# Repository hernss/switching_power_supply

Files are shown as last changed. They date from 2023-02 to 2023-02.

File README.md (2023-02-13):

# Descripción del proyecto:

El objetivo de este proyecto es desarrollar una fuente switching de voltaje variable basada en el integrado TPS54331 de Texas Instruments. Como entrada vamos a poder utilizar una fuente ATX estándar de PC o una fuentes del estilo notebook de hasta 24 volts. La fuente proveerá una salida variable entre 1.5 volts y 24 volts la cual es ajustada mediante un potenciómetro. En el caso de alimentarse con una fuente ATX también se va a disponer de las salidas de 3,3v +5v + 12v -5v -12v.
La salida esta implementadas con borneras en dos piezas, quedando el macho adherido al PCB y una parte removible a la cual se podrán conectar cables mediante tornillos.

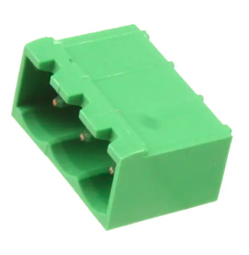
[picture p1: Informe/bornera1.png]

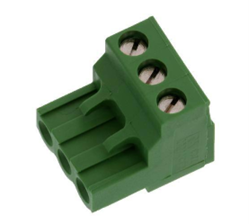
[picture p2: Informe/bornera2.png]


# Calculo de los componentes:
## Bloqueo por bajo voltaje de entrada:

* R1=  (V_START- V_STOP)/(3µA)=(6.8V-6.5V)/(3µA)=100KΩ
* R2=V_EN/((V_START- V_EN)/R1+1µA)=1.25V/((6.8V-1.25V)/100KΩ+1µA)=22123Ω

Asumo R2 = 22KΩ

## Arranque Suave:

T_SS (ms)=(C_SS (nF)x V_REF (V))/(I_SS (mA))=(10 x 0.8)/2=4 ms

## Calculo de R5 y R6:

Según la hoja de datos recomienda utilizar una resistencia de alrededor de 10K para R5, por esto asumimos inicialmente a R5 como 10K

R6 la calculamos según la siguiente ecuación:

R6=(R5 x V_REF)/(V_OUT-V_REF )

## Para obtener 4.5V a la salida:

R6=(10KΩ x 0.8V)/(4.5V-0.8V)=2162Ω 

Asumo R6 = 2.2KΩ por ser el valor comercial más cercano.

V_OUT=V_REF  x (R5/R6+1)=0.8V x (10KΩ/2.2KΩ+1)=4.44V

## Para obtener 6V a la salida:
R6=(10KΩ x 0.8V)/(6V-0.8V)=1538Ω

Como el valor comercial más cercano está muy lejos del valor que necesitamos vamos a cambiar R5 a 12K y vamos a repetir los cálculos.

R6=(12KΩ x 0.8V)/(6V-0.8V)=1845Ω

Asumo R6 = 1,8KΩ  por ser el valor comercial más cercano.

V_OUT=V_REF  x (R5/R6+1)=0.8V x (12KΩ/1.8KΩ+1)=6.13V

## Valores máximos y mínimos de la tensión de salida:

Si ahora tomamos fijo R5 = 10K y agregamos un potenciómetro de 10K con una resistencia de 330Ω en serie podemos calcular el voltaje máximo y mínimo que podemos tener a la salida.

V_MAX=V_REF  x (R5/〖R6〗_MIN +1)=0.8V x (10KΩ/330Ω+1)=25.04V

V_MIN=V_REF  x (R5/〖R6〗_MAX +1)=0.8V x (10KΩ/10330Ω+1)=1.57V

Cabe aclarar que para obtener el VMAX a la salida, la entrada tiene que tener el voltaje suficiente.

# Diagrama Esquemático:

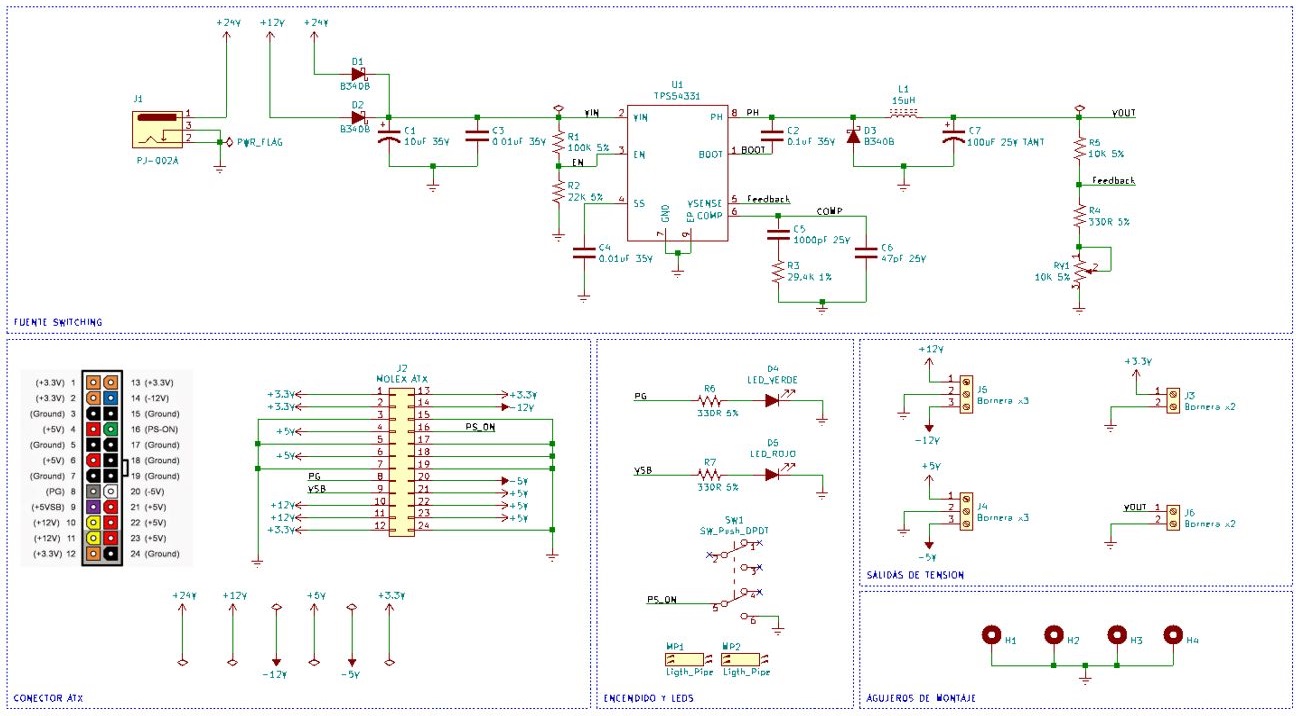
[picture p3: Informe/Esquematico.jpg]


# Circuito impreso

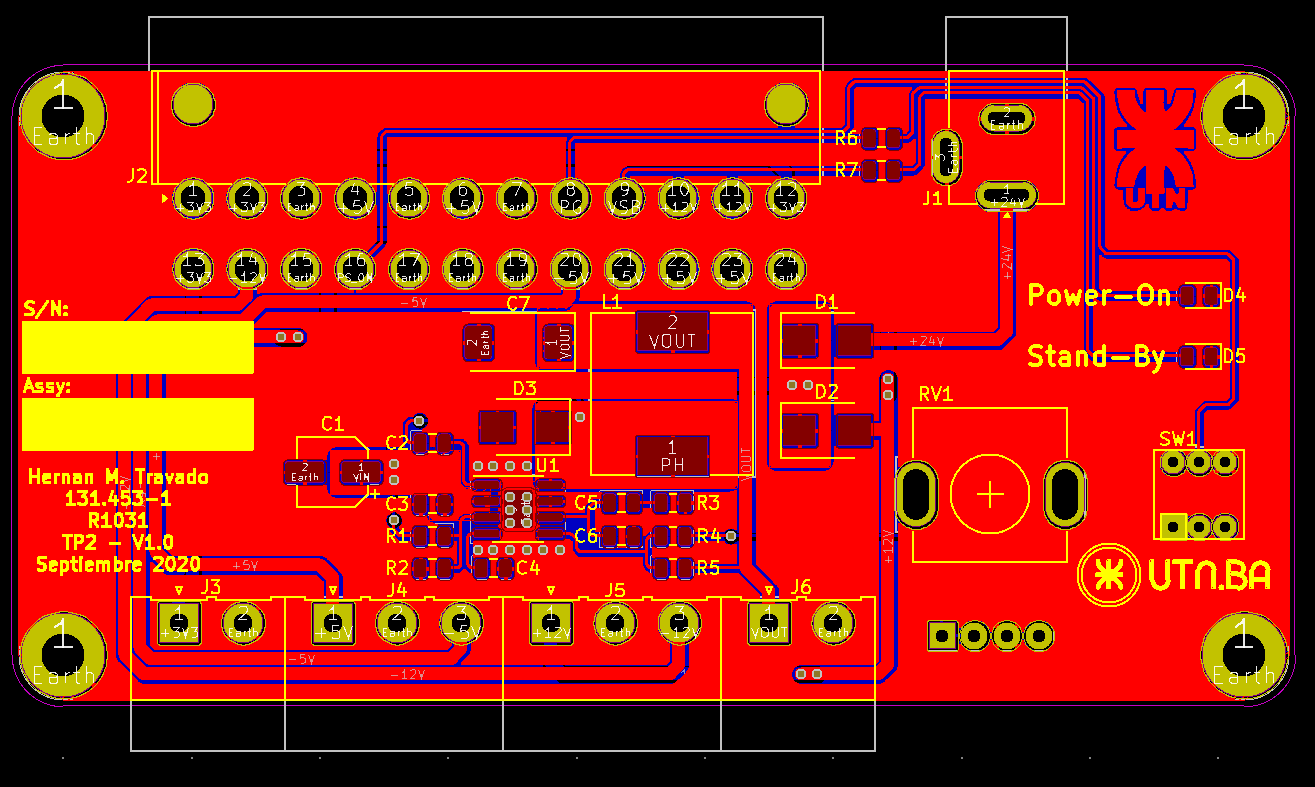
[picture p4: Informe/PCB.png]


# Vista 3D de la placa terminada

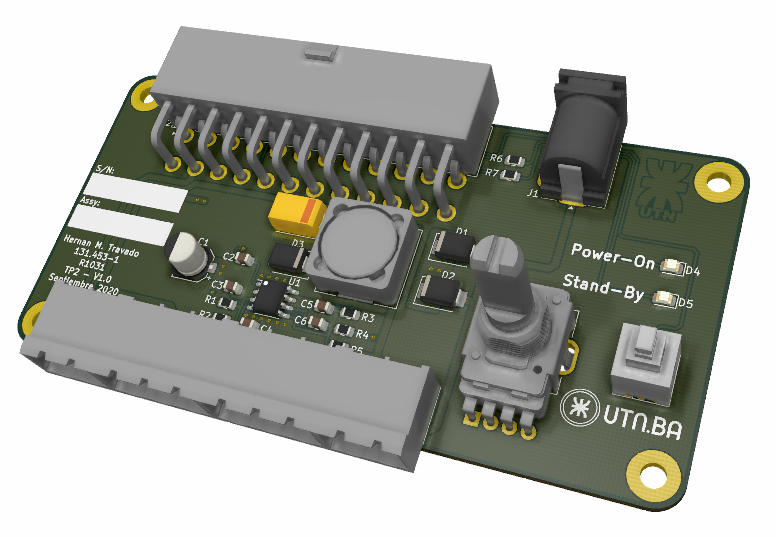
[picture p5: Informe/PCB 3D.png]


# Panelizado del PCB

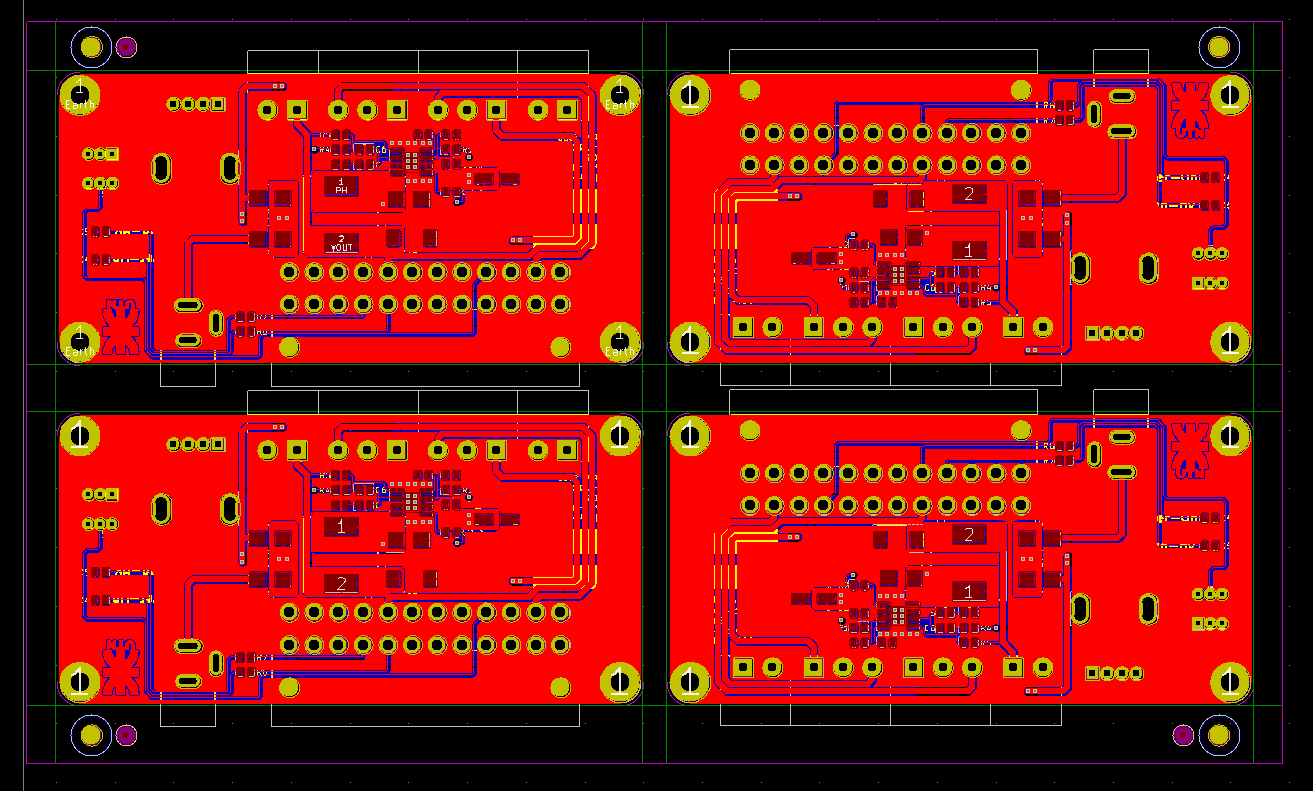
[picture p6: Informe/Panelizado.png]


# Diseño del gabinete

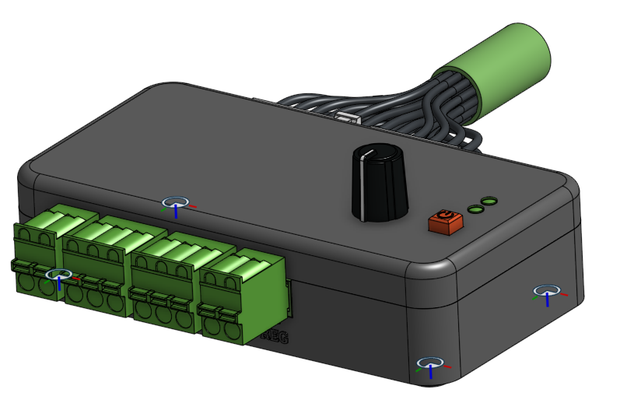
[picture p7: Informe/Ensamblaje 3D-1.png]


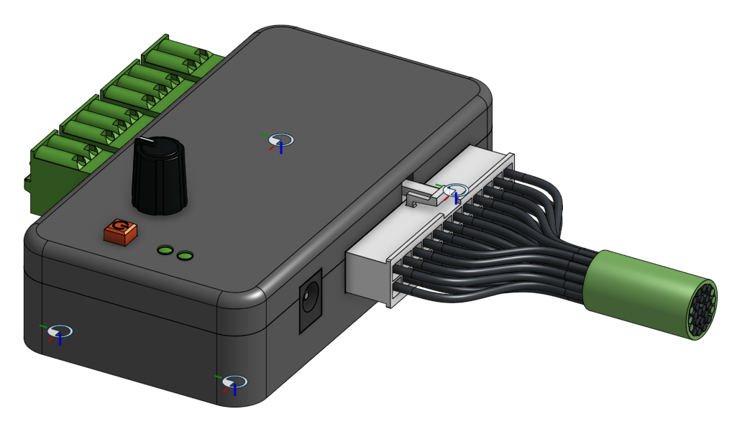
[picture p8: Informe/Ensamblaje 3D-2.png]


# Link a ON-Shape:

https://cad.onshape.com/documents/020dfdbda6882e2ac2e1fa2c/w/ac47c3931b7ff00251a716d9/e/94a10833bc3fe93f9d4dad91

# Lista de Materiales (BOM):

Cantidad	Referencia	Fabricante	Fabricante P/N	Digikey P/N

1	C1	Panasonic Electronic Components	EEE-HB1V100R	PCE4153CT-ND

1	C2	AVX Corporation	08055C104KAT2A	478-1395-1-ND

2	C3, C4	Yageo	CC0805KRX7R9BB103	311-1136-1-ND

1	C5	Samsung Electro-Mechanics	CL21B102KBANNNC	1276-1020-1-ND

1	C6	Samsung Electro-Mechanics	CL21C470JBANNNC	1276-1156-1-ND

1	C7	KEMET	T491X107K025AT	399-8410-1-ND

3	D1, D2, D3	Diodes Incorporated	B340B-13-F	B340B-FDICT-ND

1	D4	Lite-On Inc.	LTST-C170KGKT	160-1414-1-ND

1	D5	Lite-On Inc.	LTST-C171KRKT	160-1427-2-ND

1	J1	CUI Devices	PJ-002A	CP-002A-ND

1	J2	Molex	39299242	WM7334-ND

2	J3, J6	TE Connectivity AMP Connectors	796644-2	A98248-ND

2	J4, J5	TE Connectivity AMP Connectors	796644-3	A98249-ND

1	L1	Bourns Inc.	SRR1260-150M	SRR1260-150MCT-ND

2	MP1, MP2	Visual Communications Company	LFB063CTP	LFB063CTP-ND

1	R1	Yageo	RC0805JR-07100KL	311-100KARCT-ND

1	R2	Yageo	RC0805JR-0722KL	311-22KARCT-ND

1	R3	Yageo	RC0805FR-0729K4L	311-29.4KCRTR-ND

3	R4, R6, R7	Yageo	RC0805JR-07330RL	311-330RARCT-ND

1	R5	Yageo	RC0805JR-0710KL	311-10KARCT-ND

1	RV1	Bourns Inc.	PTV111-3415A-B103	PTV111-3415A-B103-ND

1	SW1	E-Switch	TL2230EEF140	EG6031-ND

1	U1	Texas Instruments	TPS54331DDAR	296-39419-1-ND

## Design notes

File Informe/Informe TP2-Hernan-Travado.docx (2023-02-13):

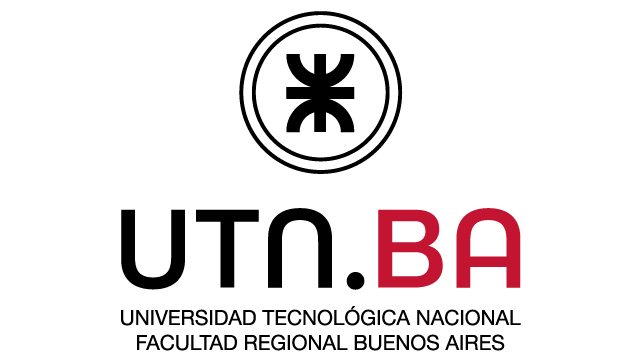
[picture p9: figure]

SISTEMAS DE REPRESENTACIÓN

Trabajo Práctico Nro. 2

Alumno: Hernán Matías Travado

Legajo: 131.453-1

Curso: R1031 – Jueves Tarde

Fecha de Entrega: 27/08/2020

Versión: 1.0

Profesores: Fernando Aló – Francisco Domínguez - Lucas Liaño

Tabla de Contenidos:

# Descripción del proyecto:

El objetivo de este proyecto es desarrollar una fuente switching de voltaje variable basada en el integrado TPS54331 de Texas Instruments. Como entrada vamos a poder utilizar una fuente ATX estándar de PC o una fuentes del estilo notebook de hasta 24 volts. La fuente proveerá una salida variable entre 1.5 volts y 24 volts la cual es ajustada mediante un potenciómetro. En el caso de alimentarse con una fuente ATX también se va a disponer de las salidas de 3,3v +5v + 12v -5v -12v.

La salida esta implementadas con borneras en dos piezas, quedando el macho adherido al PCB y una parte removible a la cual se podrán conectar cables mediante tornillos.

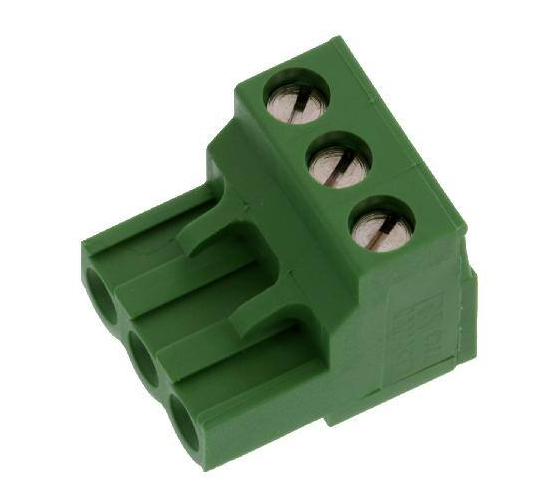
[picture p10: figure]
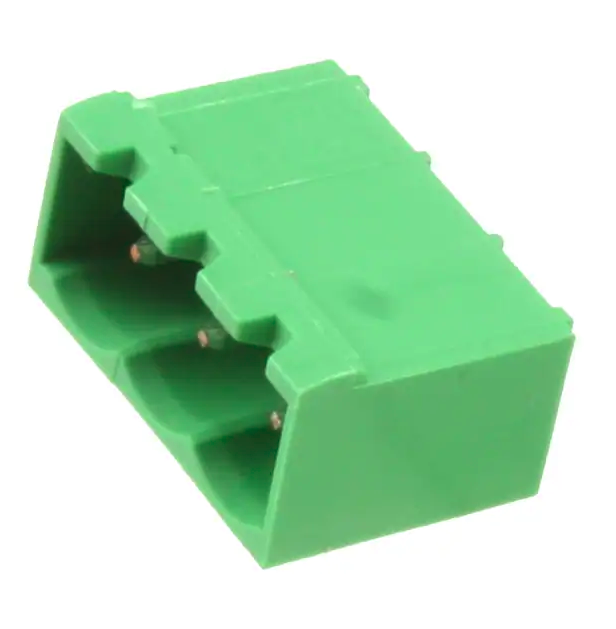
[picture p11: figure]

Detalle de las borneras de salida

# Calculo de los componentes:

## Bloqueo por bajo voltaje de entrada:

R1= (V_(START) - V_(STOP))/(3µA)=(6.8V-6.5V)/(3µA)=100KΩ

R2=(V_(EN))/((V_(START) - V_(EN))/(R1)+1µA)=(1.25V)/((6.8V-1.25V)/(100KΩ)+1µA)=22123Ω

Asumo R2 = 22KΩ

## Arranque Suave:

T_(SS) (ms)=(C_(SS) (nF)x V_(REF) (V))/(I_(SS) (mA))=(10 x 0.8)/2=4 ms

## Calculo de R5 y R6:

Según la hoja de datos recomienda utilizar una resistencia de alrededor de 10K para R5, por esto asumimos inicialmente a R5 como 10K

R6 la calculamos según la siguiente ecuación:

R6=(R5 x V_(REF))/(V_(OUT) -V_(REF))

## Para obtener 4.5V a la salida:

R6=(10KΩ x 0.8V)/(4.5V-0.8V)=2162Ω

Asumo R6 = 2.2KΩ por ser el valor comercial más cercano.

V_(OUT) =V_(REF) x ((R5)/(R6)+1)=0.8V x ((10KΩ)/(2.2KΩ)+1)=4.44V

## Para obtener 6V a la salida:

R6=(10KΩ x 0.8V)/(6V-0.8V)=1538Ω

Como el valor comercial más cercano está muy lejos del valor que necesitamos vamos a cambiar R5 a 12K y vamos a repetir los cálculos.

R6=(12KΩ x 0.8V)/(6V-0.8V)=1845Ω

Asumo R6 = 1,8KΩ por ser el valor comercial más cercano.

V_(OUT) =V_(REF) x ((R5)/(R6)+1)=0.8V x ((12KΩ)/(1.8KΩ)+1)=6.13V

## Valores máximos y mínimos de la tensión de salida:

Si ahora tomamos fijo R5 = 10K y agregamos un potenciómetro de 10K con una resistencia de 330Ω en serie podemos calcular el voltaje máximo y mínimo que podemos tener a la salida.

V_(MAX) =V_(REF) x ((R5)/(R6_(MIN))+1)=0.8V x ((10KΩ)/(330Ω)+1)=25.04V

V_(MIN) =V_(REF) x ((R5)/(R6_(MAX))+1)=0.8V x ((10KΩ)/(10330Ω)+1)=1.57V

Cabe aclarar que para obtener el VMAX a la salida, la entrada tiene que tener el voltaje suficiente.

# Estructura del ZIP entregado:

TPS54331
├── BOM | Lista de Materiales | Archivos .xls /.ods con la lista de materiales del proyecto
├── Checklist | Checklist | Checklist actualizado del proyecto
├── Gabinete | Gabinete | Proyecto onShape con el gabinete del PCB del proyecto
├── Informe | Informe | Informe de todo el proyecto en PDF
└── TPS54331 | Proyecto | Archivos de diseño del proyecto en Kicad
├── footprints | Librerías de footprints | Carpeta contenedora de librerías de footprint
│ ├── LogoUTN.pretty | Librería del proyecto | Librería de footprints con logos de la facultad
│ └── tp2.pretty | Librería del proyecto | Librería de footprints propias del proyecto
├── gerber | Gerbers | Gerbers, archivos de fabricación, drill files, etc.
├── libraries | Librería del proyecto | Librería de símbolos propias del proyecto
├── modelos3D | Modelos en 3D | Archivos .step, .stp o .wrl de los componentes
├── output | Output | Contiene la BOM en CSV y los esquemáticos en PDF
└── panel | Panel | Contiene el Panelizado del PCB
├── gerber | Gerbers | Gerbers, drill files, etc. del panel
└── modelos3D | Modelos en 3D | Archivos .step, .stp o .wrl de los componentes

# Diagrama Esquemático:

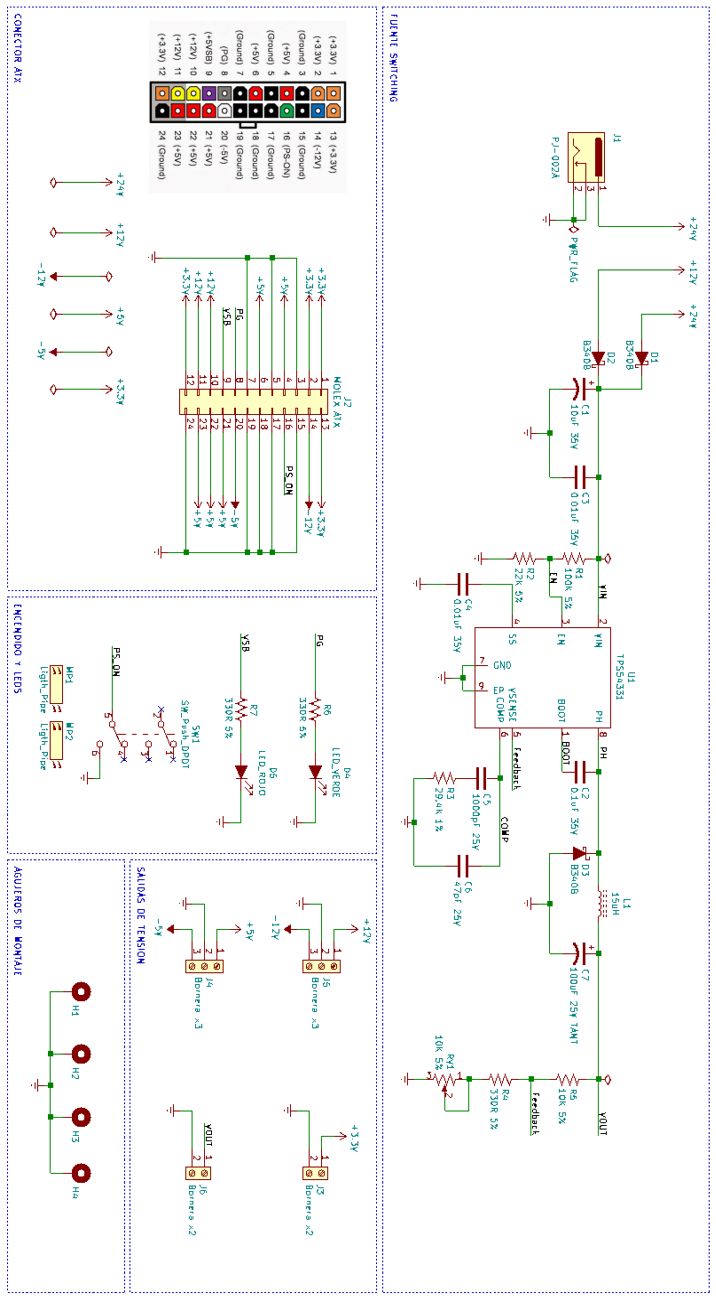
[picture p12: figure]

# Circuito Impreso:


# Vista 3D de la placa terminada:


# Panelizado del PCB:


# Lista de Materiales (BOM):

Cantidad | Referencia | Fabricante | Fabricante P/N | Digikey P/N
1 | C1 | Panasonic Electronic Components | EEE-HB1V100R | PCE4153CT-ND
1 | C2 | AVX Corporation | 08055C104KAT2A | 478-1395-1-ND
2 | C3, C4 | Yageo | CC0805KRX7R9BB103 | 311-1136-1-ND
1 | C5 | Samsung Electro-Mechanics | CL21B102KBANNNC | 1276-1020-1-ND
1 | C6 | Samsung Electro-Mechanics | CL21C470JBANNNC | 1276-1156-1-ND
1 | C7 | KEMET | T491X107K025AT | 399-8410-1-ND
3 | D1, D2, D3 | Diodes Incorporated | B340B-13-F | B340B-FDICT-ND
1 | D4 | Lite-On Inc. | LTST-C170KGKT | 160-1414-1-ND
1 | D5 | Lite-On Inc. | LTST-C171KRKT | 160-1427-2-ND
1 | J1 | CUI Devices | PJ-002A | CP-002A-ND
1 | J2 | Molex | 39299242 | WM7334-ND
2 | J3, J6 | TE Connectivity AMP Connectors | 796644-2 | A98248-ND
2 | J4, J5 | TE Connectivity AMP Connectors | 796644-3 | A98249-ND
1 | L1 | Bourns Inc. | SRR1260-150M | SRR1260-150MCT-ND
2 | MP1, MP2 | Visual Communications Company | LFB063CTP | LFB063CTP-ND
1 | R1 | Yageo | RC0805JR-07100KL | 311-100KARCT-ND
1 | R2 | Yageo | RC0805JR-0722KL | 311-22KARCT-ND
1 | R3 | Yageo | RC0805FR-0729K4L | 311-29.4KCRTR-ND
3 | R4, R6, R7 | Yageo | RC0805JR-07330RL | 311-330RARCT-ND
1 | R5 | Yageo | RC0805JR-0710KL | 311-10KARCT-ND
1 | RV1 | Bourns Inc. | PTV111-3415A-B103 | PTV111-3415A-B103-ND
1 | SW1 | E-Switch | TL2230EEF140 | EG6031-ND
1 | U1 | Texas Instruments | TPS54331DDAR | 296-39419-1-ND

# Link a Octopart:

https://octopart.com/bom-tool/RoDDKawv

# Gabinete en 3D:


# Link a ON-Shape:

https://cad.onshape.com/documents/020dfdbda6882e2ac2e1fa2c/w/ac47c3931b7ff00251a716d9/e/94a10833bc3fe93f9d4dad91

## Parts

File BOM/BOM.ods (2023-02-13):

Qty | Reference(s) | Value | Datasheet | Digikey P/N | Manufacturer | Manufacturer P/N | Mouser P/N
1 | C1 | 10uF 35V | https://industrial.panasonic.com/cdbs/www-data/pdf/RDE0000/ABA0000C1157.pdf | PCE4153CT-ND | Panasonic Electronic Components | EEE-HB1V100R
1 | C2 | 0.1uF 35V | http://datasheets.avx.com/X7RDielectric.pdf | 478-1395-1-ND | AVX Corporation | 08055C104KAT2A
2 | C3, C4 | 0.01uF 35V | https://www.yageo.com/upload/media/product/productsearch/datasheet/mlcc/UPY-GPHC_X7R_6.3V-to-50V_18.pdf | 311-1136-1-ND | Yageo | CC0805KRX7R9BB103
1 | C5 | 1000pF 25V | https://media.digikey.com/pdf/Data%20Sheets/Samsung%20PDFs/CL_Series_MLCC_ds.pdf | 1276-1020-1-ND | Samsung Electro-Mechanics | CL21B102KBANNNC
1 | C6 | 47pF 25V | https://media.digikey.com/pdf/Data%20Sheets/Samsung%20PDFs/CL_Series_MLCC_ds.pdf | 1276-1156-1-ND | Samsung Electro-Mechanics | CL21C470JBANNNC
1 | C7 | 100uF 25V TANT | https://api.kemet.com/component-edge/download/datasheet/T491X107K025AT.pdf | 399-8410-1-ND | KEMET | T491X107K025AT
3 | D1, D2, D3 | B340B | https://media.digikey.com/pdf/Data%20Sheets/Diodes%20PDFs/B320B-B360B_Rev10-2.pdf | B340B-FDICT-ND | Diodes Incorporated | B340B-13-F | 621-B340B-F
1 | D4 | LED_VERDE | http://optoelectronics.liteon.com/upload/download/DS22-2000-073/LTST-C170KGKT.pdf | 160-1414-1-ND | Lite-On Inc. | LTST-C170KGKT
1 | D5 | LED_ROJO | http://optoelectronics.liteon.com/upload/download/DS22-2000-073/LTST-C170KGKT.pdf | 160-1427-2-ND | Lite-On Inc. | LTST-C171KRKT
4 | H1, H2, H3, H4 | MountingHole_Pad | ~
1 | J1 | PJ-002A | https://www.cuidevices.com/product/resource/digikeypdf/pj-002a.pdf | CP-002A-ND | CUI Devices | PJ-002A
1 | J2 | MOLEX ATX | https://www.molex.com/pdm_docs/sd/039299022_sd.pdf | WM7334-ND | Molex | 39299242
2 | J3, J6 | Bornera x2 | https://www.te.com/commerce/DocumentDelivery/DDEController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 | A98248-ND | TE Connectivity AMP Connectors | 796644-2
2 | J4, J5 | Bornera x3 | https://www.te.com/commerce/DocumentDelivery/DDEController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 | A98249-ND | TE Connectivity AMP Connectors | 796644-3
1 | L1 | 15uH | https://www.bourns.com/docs/Product-Datasheets/SRR1260.pdf | SRR1260-150MCT-ND | Bourns Inc. | SRR1260-150M
2 | MP1, MP2 | Ligth_Pipe | http://www.vcclite.com/_pdf/LFBSeries.pdf | LFB063CTP-ND | Visual Communications Company - VCC | LFB063CTP
1 | R1 | 100K 5% | https://www.yageo.com/upload/media/product/productsearch/datasheet/rchip/PYu-RC_Group_51_RoHS_L_10.pdf | 311-100KARCT-ND | Yageo | RC0805JR-07100KL
1 | R2 | 22K 5% | https://www.yageo.com/upload/media/product/productsearch/datasheet/rchip/PYu-RC_Group_51_RoHS_L_10.pdf | 311-22KARCT-ND | Yageo | RC0805JR-0722KL
1 | R3 | 29.4K 1% | https://www.yageo.com/upload/media/product/productsearch/datasheet/rchip/PYu-RC_Group_51_RoHS_L_10.pdf | 311-29.4KCRTR-ND | Yageo | RC0805FR-0729K4L
3 | R4, R6, R7 | 330R 5% | https://www.yageo.com/upload/media/product/productsearch/datasheet/rchip/PYu-RC_Group_51_RoHS_L_10.pdf | 311-330RARCT-ND | Yageo | RC0805JR-07330RL
1 | R5 | 10K 5% | https://www.yageo.com/upload/media/product/productsearch/datasheet/rchip/PYu-RC_Group_51_RoHS_L_10.pdf | 311-10KARCT-ND | Yageo | RC0805JR-0710KL
1 | RV1 | 10K 5% | https://www.bourns.com/docs/Product-Datasheets/PTVPTT.pdf | PTV111-3415A-B103-ND | Bourns Inc. | PTV111-3415A-B103
1 | SW1 | SW_Push_DPDT | https://sten-eswitch-13110800-production.s3.amazonaws.com/system/asset/product_line/data_sheet/61/TL2201.pdf | EG6031-ND | E-Switch | TL2230EEF140
1 | U1 | TPS54331 | http://www.ti.com/general/docs/suppproductinfo.tsp?distId=10 | 296-39419-1-ND | Texas Instruments | TPS54331DDAR

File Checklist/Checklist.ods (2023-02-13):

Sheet: Completa
# | Ubicación de componentes | Comentarios | Cumple / No cumple / No aplica
1 | Orientación consistente de componentes SMD |  | Cumple
2 | Espacio para herramientas de retrabajo y extraccion de ICs |  | Cumple
3 | Verificar componentes polarizados |  | Cumple
4 | Utilizar grilla de 50 mil (o 1.25mm) para componentes THT y 20 mils (o 0.5mm) para SMD |  | Cumple
5 | Verificar orientación de todos los conectores |  | Cumple
6 | Verificar espacio mínimo entre cuerpo de componentes |  | Cumple
7 | Capacitores de desacople (bypass) cerca de pines de alimentación de los IC |  | Cumple
8 | Verificar terminadores en serie cercanos a la fuente |  | Cumple
9 | Drivers I/O cercanos a donde las señales abandonan el PCB |  | No Aplica
10 | Pistas de alimentación y test points, todos etiquetados. | No se utilizaron testpoints. | Cumple
11 | Filtros EMI y RFI lo más cerca posible a puntos de entrada y salida en áreas blindadas. | No se utilizaron filtros EMI ni RFI | No Aplica
12 | Verificar que los potenciómetros incrementar la cantidad controlada en sentido de las agujas del reloj. |  | Cumple
13 | Verificar si los orificios de montaje deben estar aislados eléctricamente o no. | Los orificios de montaje estan conectados a la masa del circuito. | Cumple
14 | Verificar distancia de seguridad de los orificios de montaje hacia otros componentes. |  | Cumple
15 | Verificar factor de forma de los pads SMD. |  | Cumple
16 | Fiduciales locales y en panel para ensamle automático. | No se colocaron fiduciales en la placa, solo se colocaron en el panel | Cumple
17 | Distancia de seguridad suficiente para ICs con zócalo. | No hay ICs con zocalo | No Aplica
# | Ruteo/pistas | Comentarios | Cumple / No cumple / No aplica
18 | Comunes digitales y analógicos unidos en un solo punto. | No hay lineas analogicas. | No Aplica
19 | Verificar pistas debajo de componentes ruidosos o sensibles. |  | No Aplica
20 | No ubicar vias debajo de resistores de metalfilm u otros componentes con aislación pobre. |  | Cumple
21 | Verificar pistas susceptibles a puentes de soldadura. |  | Cumple
22 | Verificar pistas sin conexión en un extremo, a menos que sea a propósito. |  | Cumple
23 | Asegurar que el CAD unifica o no señales Vcc/Vdd y Vss/GND según lo requiera el diseño. |  | Cumple
24 | Utilizar múltiples vías en pistas de alta corriente y/o baja impedancia. | Se utilizaron dos vias en las pistas de alimentacion | Cumple
25 | Observar keepout de componentes y pistas. | No hay componentes con zonas de keepout | No Aplica
26 | Utilizar planos de GND donde sea posible. |  | Cumple
# | Dimensiones | Comentarios | Cumple / No cumple / No aplica
27 | Diámetro de orificios debe considerar el metalizado. |  | Cumple
28 | Diámetro de orificios más grande que el diámetro de pata al menos en 10 mils. |  | Cumple
29 | Ancho de texto en silkscreen 0.20mm o más. |  | Cumple
30 | Pad al menos 0.4mm más grande que drill. |  | Cumple
31 | Componentes ubicados al menos a 1mm del borde del PCB. | A excepcion de las borneras ya que estas sobresalen del gabinete | Cumple
32 | Test point ubicados al menos a 5mm del borde del PCB. | No se colocaron testpoints en la placa | No Aplica
33 | Pistas al menos a 0.5mm del borde del PCB. |  | Cumple
34 | Tolerancia de drills especificada. | No se necesita trabajar con tolerancias especiales | No Aplica
35 | Tolerancia de máscara antisoldante especificada. | No se necesita trabajar con tolerancias especiales | No Aplica
36 | Tolerancia de pistas especificada. | No se necesita trabajar con tolerancias especiales | No Aplica
37 | Tolerancia de serigrafía especificada. | No se necesita trabajar con tolerancias especiales | No Aplica
38 | Ancho de pista suficiente para la corriente que conduce. |  | Cumple
39 | Distancia suficiente entre pistas de alto voltaje. | No hay señales de alto voltaje | No Aplica
# | Serigrafía (silkscreen) | Comentarios | Cumple / No cumple / No aplica
40 | Evitar serigrafía sobre vías u orificios. |  | Cumple
41 | Todos los textos y leyendas legibles en una o dos direcciones. |  | Cumple
42 | Logo de la compañía en serigrafía y/o en cobre (logo de la facultad en nuestro caso) |  | Cumple
43 | Nota de copyright en PCB. | No tiene copyright | No Aplica
44 | Fecha en PCB. |  | Cumple
45 | Número de parte en PCB. (en nuesto caso TP1/TP2, etc) |  | Cumple
46 | Revisión del PCB en serigrafía. (v1.0 o R01) |  | Cumple
47 | Espacio para revisión de montaje en serigrafía. (ASSY) |  | Cumple
48 | Espacio para número de serie en serigrafía. (S/N) |  | Cumple
49 | Ubicar todo el texto de la serigrafía de manera tal que sea legible cuando los componentes están montados. |  | Cumple
50 | Todos los ICs deben tener el pin 1 debidamente marcado y visible con el IC instalado. |  | Cumple
51 | ICs de muchos pines deberían tener los pines extremos numerados para facilitar su identificación. | No hay ICs con muchos pines | No Aplica
52 | Marcas cada 5 o 10 pines en ICs o conectores de muchos pines para facilitar su identificación. | No hay ICs con muchos pines | No Aplica
# | Otros | Comentarios | Cumple / No cumple / No aplica
53 | Utilizar DRC y ERC habilitados en el CAD. (chequeo de errores en esquemático y PCB) | Ambos libres de errores | Cumple
54 | Tomar las precauciones necesarias en circuitos de alta frecuencia. | No es un circuito de alta frecuencia | No Aplica
55 | Colocar conectores y pines extra en prototipos para pruebas, por si es necesario. | No es necesarios agregar ningun pin extra | No Aplica
56 | Verificar dimensiones y formas de orificios en conectores raros (rectangulares, ovalados). |  | Cumple
57 | Verificar si la máscara antisoldante cubre o no cubre las vías. | La mascara antisoldando cubre las vias | Cumple
58 | No rutear ángulos agudos. |  | Cumple
59 | Verificar profundidad de la máscara antisoldante. |  | Cumple
60 | Verificar el netlist manualmente o por inspección visual. |  | Cumple
61 | Verificar si el origen de orificios es un pad de referencia.
62 | Anotar en layer auxiliar ancho del PCB, material y espesor del cobre. |  | Cumple
63 | Utilizar aislamiento térmico (thermal relief) en capas internas de distribución de alimentación. |  | Cumple
64 | Verificar que las aperturas para pasta de estaño sean del tamaño adecuado. |  | Cumple
65 | Verificar si se permiten blind/buried vias en PCB multicapa. | No se utilizaron ese tipo de vias | No Aplica
66 | Definir correctamente el panelizado del PCB. |  | Cumple
67 | Encapsulados metálicos de cristales de alta frecuencia deberían conectarse a GND. | No hay cristales de alta frecuencia en la placa | No Aplica

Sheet: Reducida
# | Ubicación de componentes | Comentarios | Cumple / No cumple / No aplica
1 | Orientación consistente de componentes SMD
2 | Espacio para herramientas de retrabajo y extraccion de ICs
3 | Verificar componentes polarizados
4 | Utilizar grilla de 50 mil (o 1.25mm) para componentes THT y 20 mils (o 0.5mm) para SMD
5 | Verificar orientación de todos los conectores
6 | Verificar espacio mínimo entre cuerpo de componentes
7 | Capacitores de desacople (bypass) cerca de pines de alimentación de los IC
8 | Pistas de alimentación y test points, todos etiquetados.
9 | Verificar que los potenciómetros incrementar la cantidad controlada en sentido de las agujas del reloj.
10 | Verificar distancia de seguridad de los orificios de montaje hacia otros componentes.
11 | Fiduciales locales y en panel para ensamle automático.
# | Ruteo/pistas | Comentarios | Cumple / No cumple / No aplica
12 | Verificar pistas debajo de componentes ruidosos o sensibles.
13 | Verificar pistas sin conexión en un extremo, a menos que sea a propósito.
14 | Utilizar múltiples vías en pistas de alta corriente y/o baja impedancia.
15 | Observar keepout de componentes y pistas.
16 | Utilizar planos de GND donde sea posible.
# | Dimensiones | Comentarios | Cumple / No cumple / No aplica
17 | Ancho de texto en silkscreen 0.20mm o más.
18 | Componentes ubicados al menos a 1mm del borde del PCB.
19 | Test point ubicados al menos a 5mm del borde del PCB.
20 | Pistas al menos a 0.5mm del borde del PCB.
21 | Ancho de pista suficiente para la corriente que conduce.
# | Serigrafía (silkscreen) | Comentarios | Cumple / No cumple / No aplica
22 | Evitar serigrafía sobre vías u orificios.
23 | Todos los textos y leyendas legibles en una o dos direcciones.
24 | Logo de la compañía en serigrafía y/o en cobre (logo de la facultad en nuestro caso)
25 | Nota de copyright en PCB.
26 | Fecha en PCB.
27 | Número de parte en PCB. (en nuesto caso TP1/TP2, etc)
28 | Revisión del PCB en serigrafía. (v1.0 o R01)
29 | Espacio para revisión de montaje en serigrafía. (ASSY)
30 | Espacio para número de serie en serigrafía. (S/N)
31 | Ubicar todo el texto de la serigrafía de manera tal que sea legible cuando los componentes están montados.
32 | Todos los ICs deben tener el pin 1 debidamente marcado y visible con el IC instalado.
33 | ICs de muchos pines deberían tener los pines extremos numerados para facilitar su identificación.
34 | Marcas cada 5 o 10 pines en ICs o conectores de muchos pines para facilitar su identificación.
# | Otros | Comentarios | Cumple / No cumple / No aplica
35 | Utilizar DRC y ERC habilitados en el CAD. (chequeo de errores en esquemático y PCB)
36 | Verificar si la máscara antisoldante cubre o no cubre las vías.
37 | No rutear ángulos agudos.
38 | Anotar en layer auxiliar ancho del PCB, material y espesor del cobre.
39 | Utilizar aislamiento térmico (thermal relief) en capas internas de distribución de alimentación.
40 | Definir correctamente el panelizado del PCB.

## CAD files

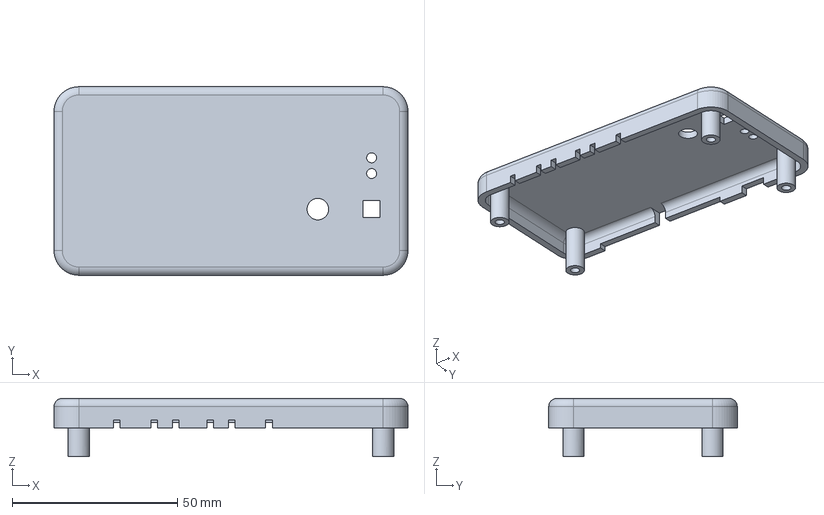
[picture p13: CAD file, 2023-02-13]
Gabinete/Gabinete - Tapa Gabinete.step
107.0 x 57.0 x 17.6 mm

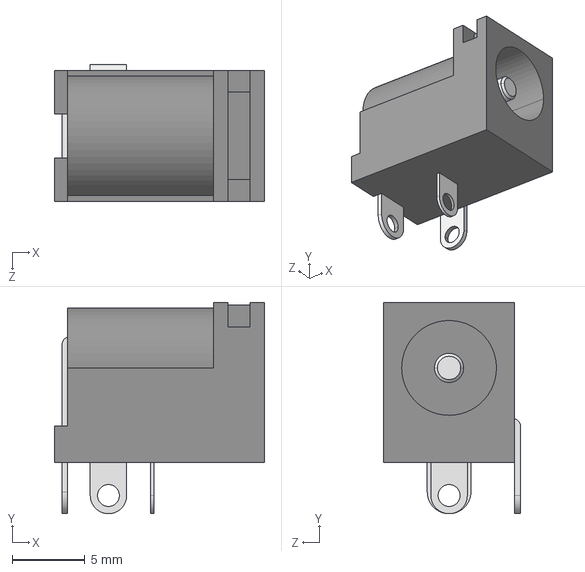
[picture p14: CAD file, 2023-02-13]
TPS54331-KiCad Files/panel/modelos3D/PJ-002A.step
14.4 x 14.5 x 9.40 mm

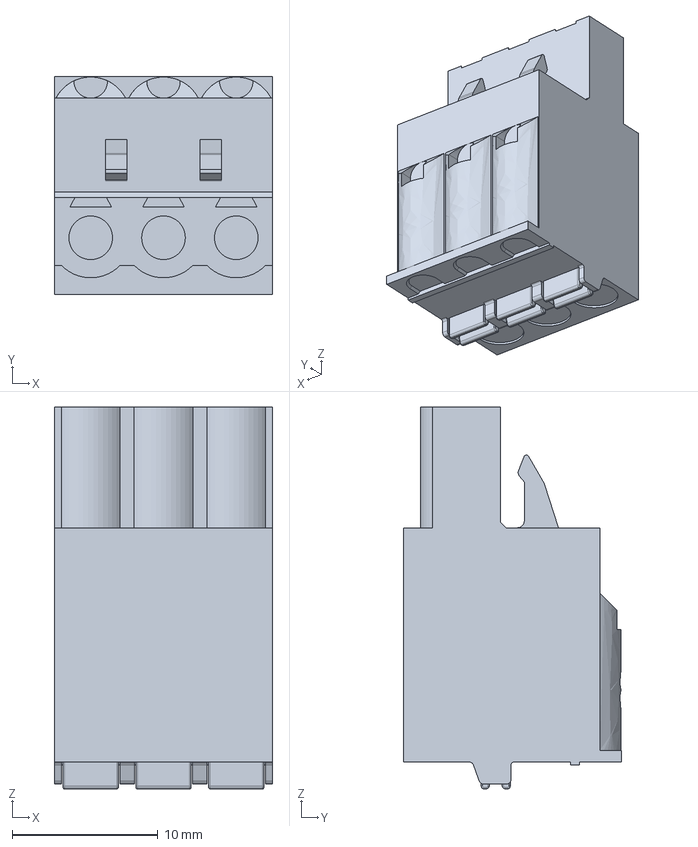
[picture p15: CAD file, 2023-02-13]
Gabinete/Conector Bornera 3pines.igs
15.0 x 15.0 x 26.3 mm

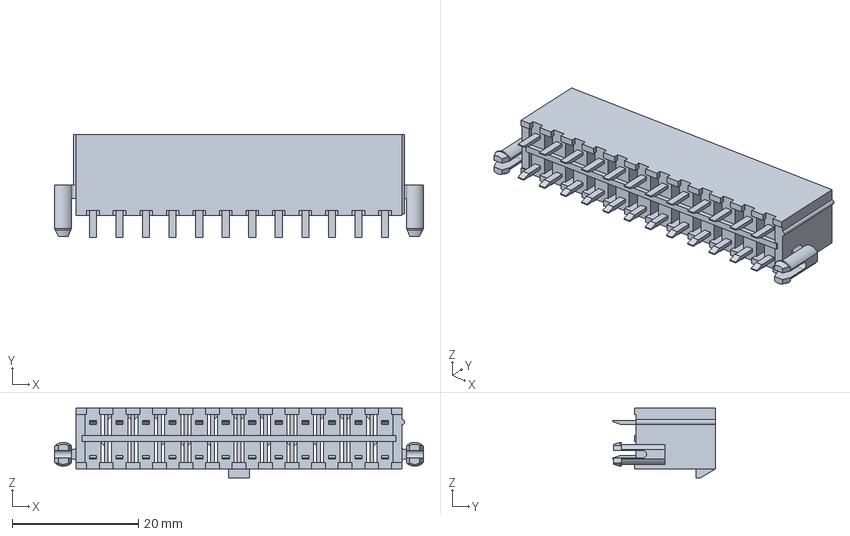
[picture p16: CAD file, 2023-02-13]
TPS54331-KiCad Files/modelos3D/molex_039299242.stp
58.4 x 16.3 x 11.0 mm

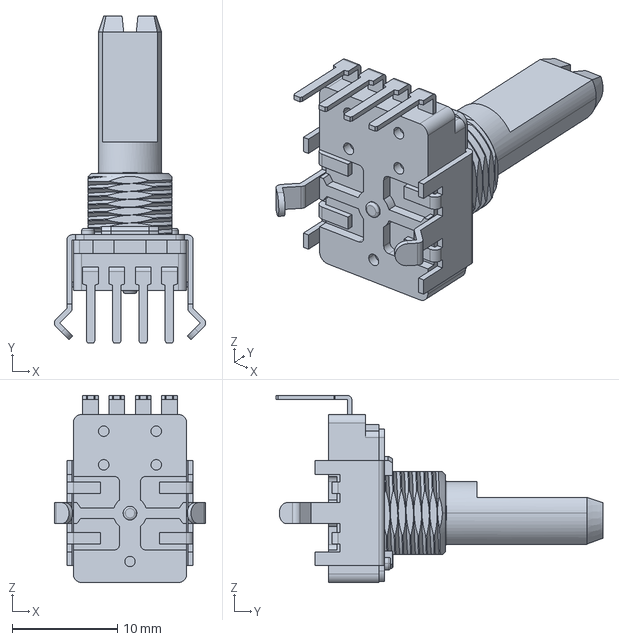
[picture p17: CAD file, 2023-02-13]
TPS54331-KiCad Files/panel/modelos3D/PTV111-3.stp
14.4 x 31.1 x 17.8 mm

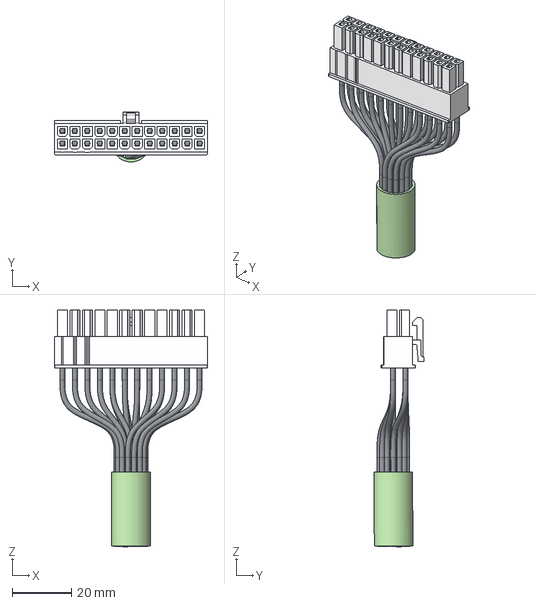
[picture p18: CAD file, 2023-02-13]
Gabinete/Conector ATX - 039012240.step
51.6 x 16.8 x 79.8 mm

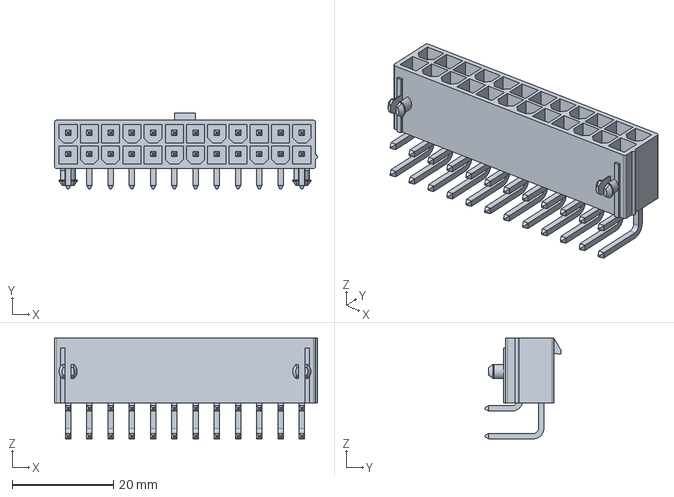
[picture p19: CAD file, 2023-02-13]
TPS54331-KiCad Files/modelos3D/molex_039301240.stp
52.0 x 15.0 x 19.9 mm

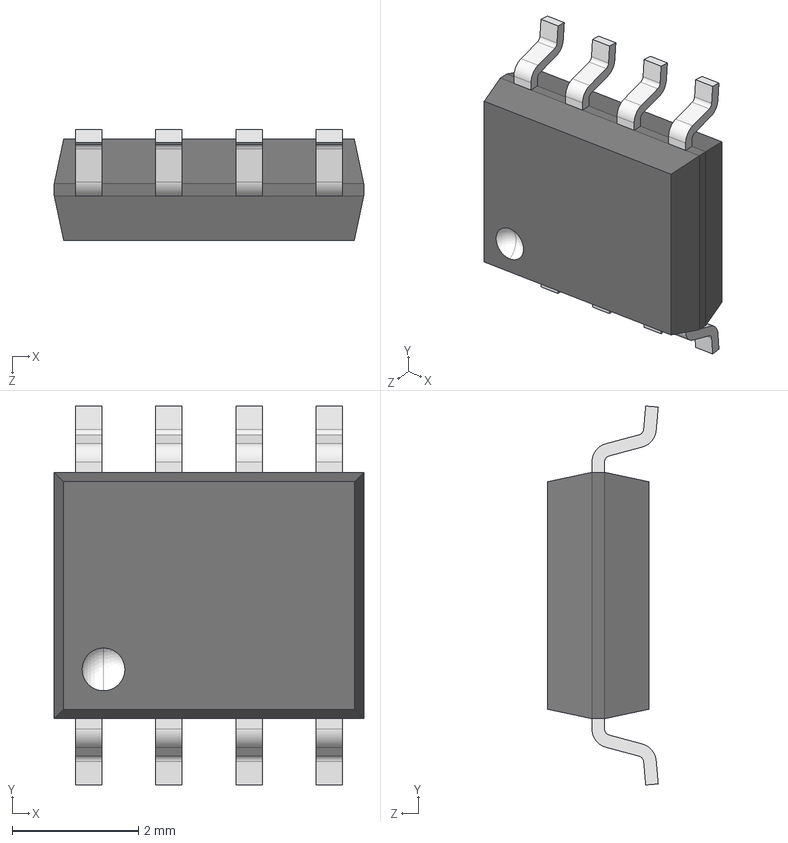
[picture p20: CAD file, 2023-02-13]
TPS54331-KiCad Files/panel/modelos3D/SOIC-8-1.step
4.90 x 6.00 x 1.75 mm

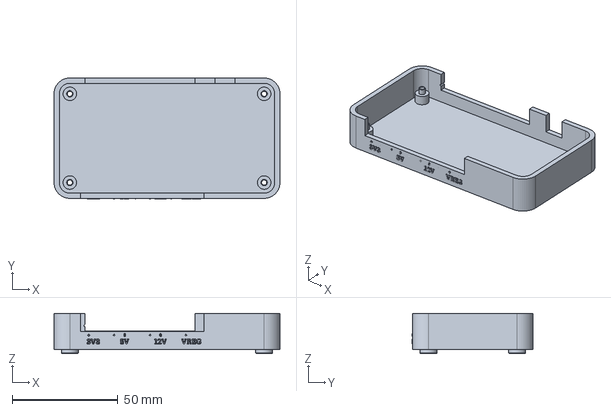
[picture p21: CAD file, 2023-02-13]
Gabinete/Gabinete - Base Gabinete.step
107.0 x 57.3 x 19.1 mm

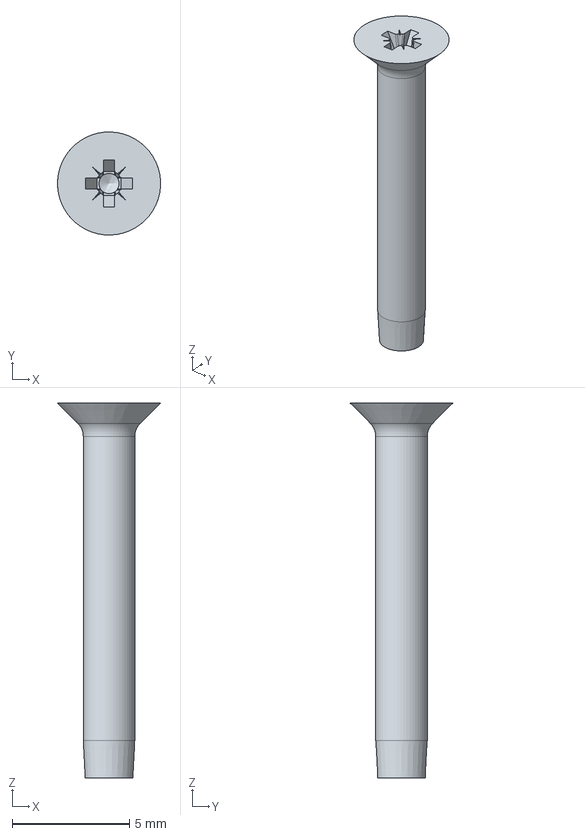
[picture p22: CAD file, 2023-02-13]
Gabinete/Tornillo Gabinete.step
4.40 x 4.40 x 16.0 mm

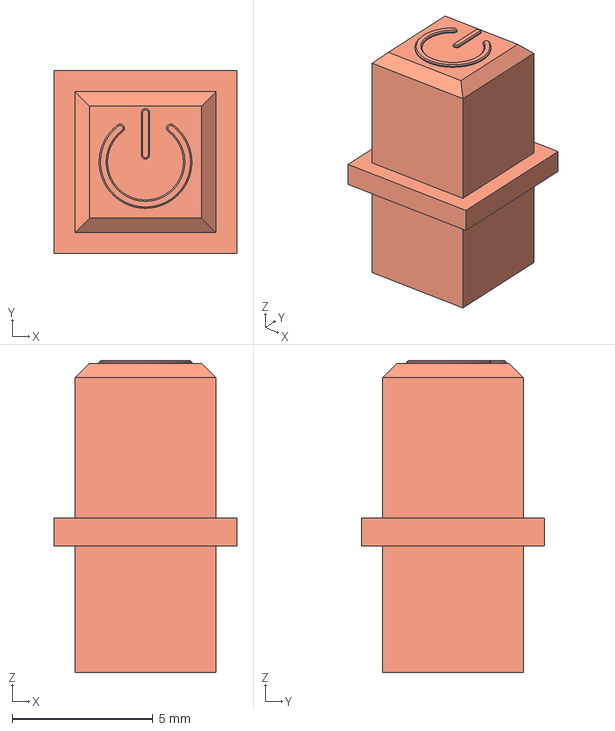
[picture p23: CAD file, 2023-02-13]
Gabinete/Pulsador - Tecla Encendido.step
6.50 x 6.50 x 11.1 mm

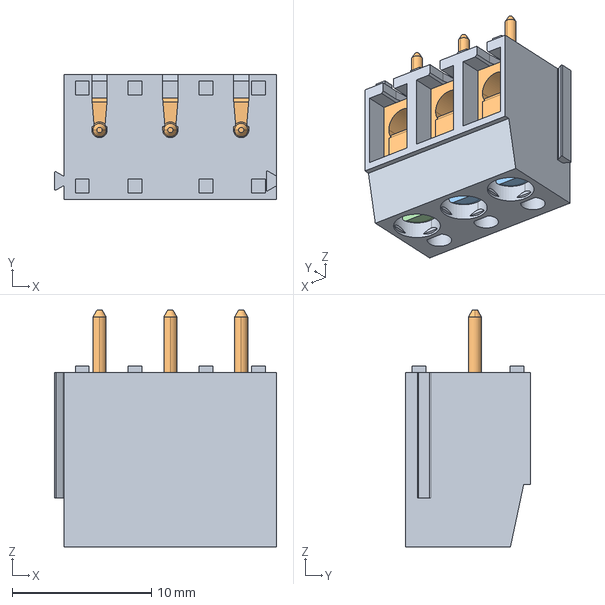
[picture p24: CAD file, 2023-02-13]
TPS54331-KiCad Files/modelos3D/OSTTA034163.stp
15.9 x 9.00 x 17.0 mm

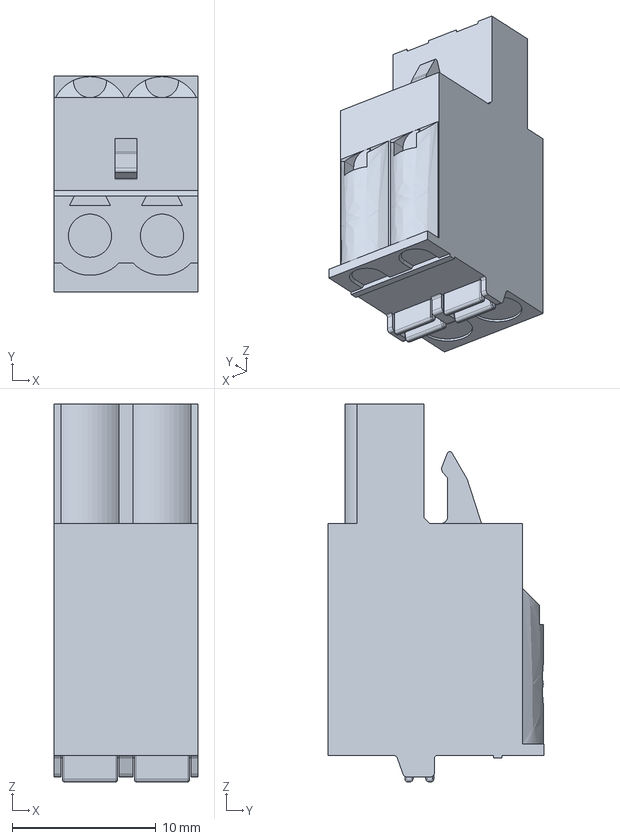
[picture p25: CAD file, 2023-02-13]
Gabinete/Conector Bornera 2pines.igs
10.0 x 15.0 x 26.3 mm

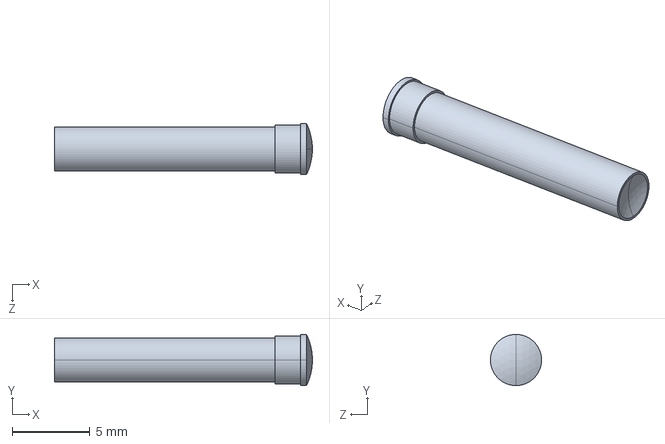
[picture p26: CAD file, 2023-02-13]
Gabinete/Ligth Pipe 063.STEP
16.6 x 3.30 x 3.30 mm

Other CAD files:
TPS54331-KiCad Files/modelos3D/039012240.stp
TPS54331-KiCad Files/modelos3D/282814-2.stp
TPS54331-KiCad Files/modelos3D/282814-3.stp
TPS54331-KiCad Files/modelos3D/47021.stp
TPS54331-KiCad Files/modelos3D/796638-2.stp
TPS54331-KiCad Files/modelos3D/796638-3.stp
TPS54331-KiCad Files/modelos3D/796644-2.stp
TPS54331-KiCad Files/modelos3D/796644-3.stp
TPS54331-KiCad Files/modelos3D/Generic POT.step
TPS54331-KiCad Files/modelos3D/TL2230.stp
TPS54331-KiCad Files/modelos3D/srr1260.stp
TPS54331-KiCad Files/panel/modelos3D/282814-2.stp
TPS54331-KiCad Files/panel/modelos3D/282814-3.stp
TPS54331-KiCad Files/panel/modelos3D/796638-2.stp
TPS54331-KiCad Files/panel/modelos3D/796638-3.stp
TPS54331-KiCad Files/panel/modelos3D/796644-2.stp
TPS54331-KiCad Files/panel/modelos3D/796644-3.stp
TPS54331-KiCad Files/panel/modelos3D/Generic POT.step
TPS54331-KiCad Files/panel/modelos3D/TL2230.stp
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

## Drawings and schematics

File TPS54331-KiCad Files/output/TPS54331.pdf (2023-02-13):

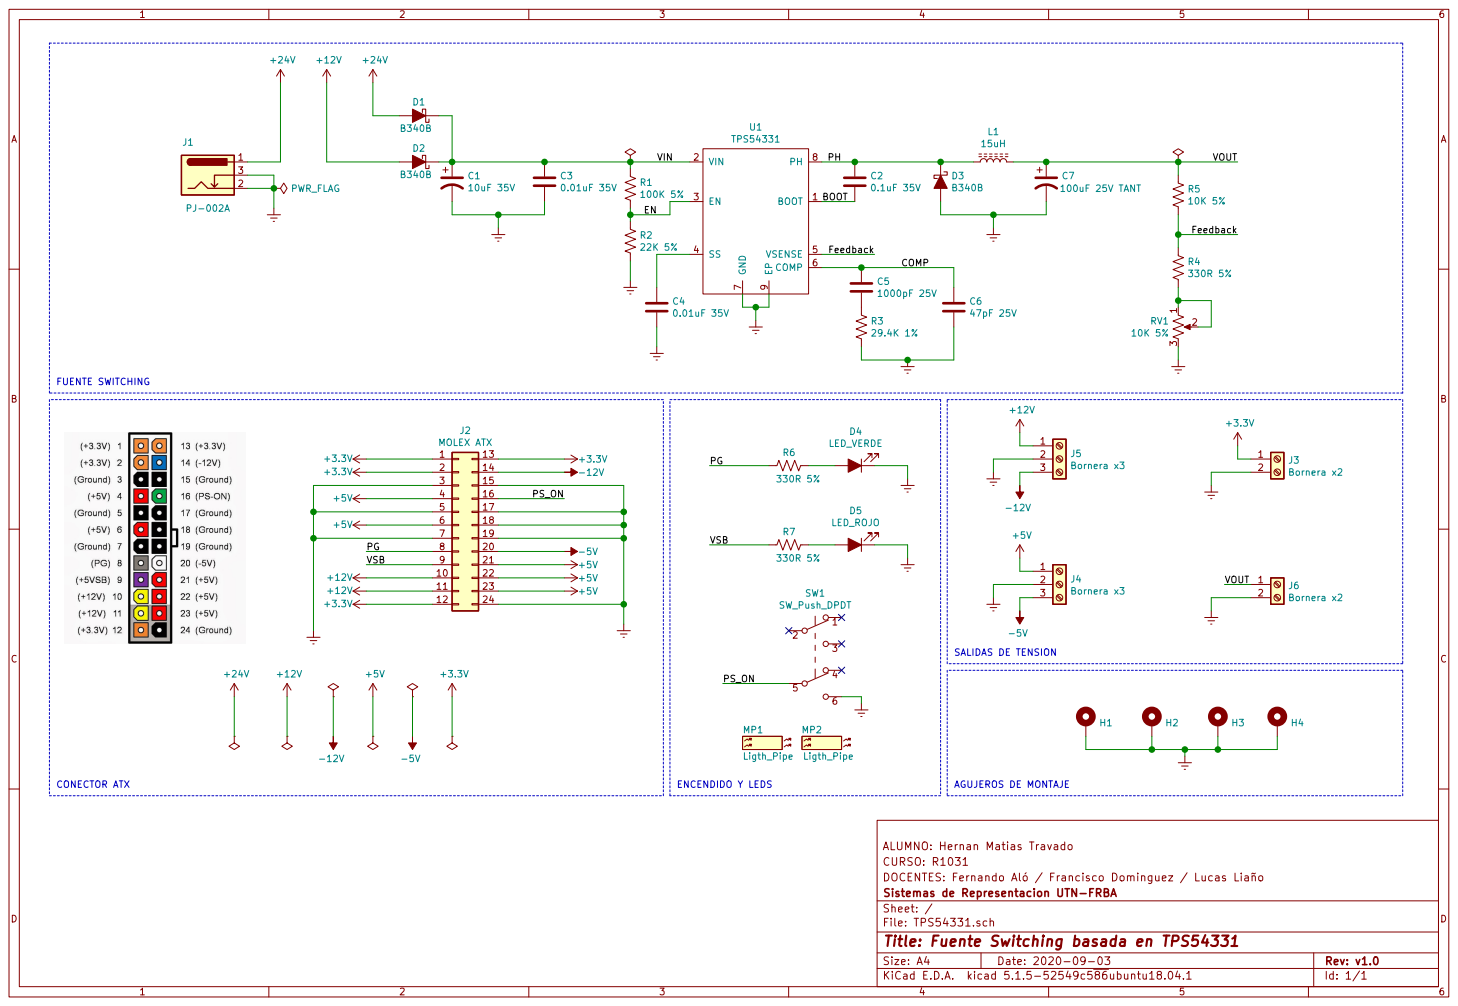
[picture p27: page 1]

VOUT AGUJEROS DE MONTAJE
BOOT VSB

DOCENTES: Fernando Aló / Francisco Dominguez / Lucas Liaño CURSO: R1031 ALUMNO: Hernan Matias Travado

File: TPS54331.sch Sheet: / Sistemas de Representacion UTN-FRBA

Id: 1/1 Title: Fuente Switching basada en TPS54331

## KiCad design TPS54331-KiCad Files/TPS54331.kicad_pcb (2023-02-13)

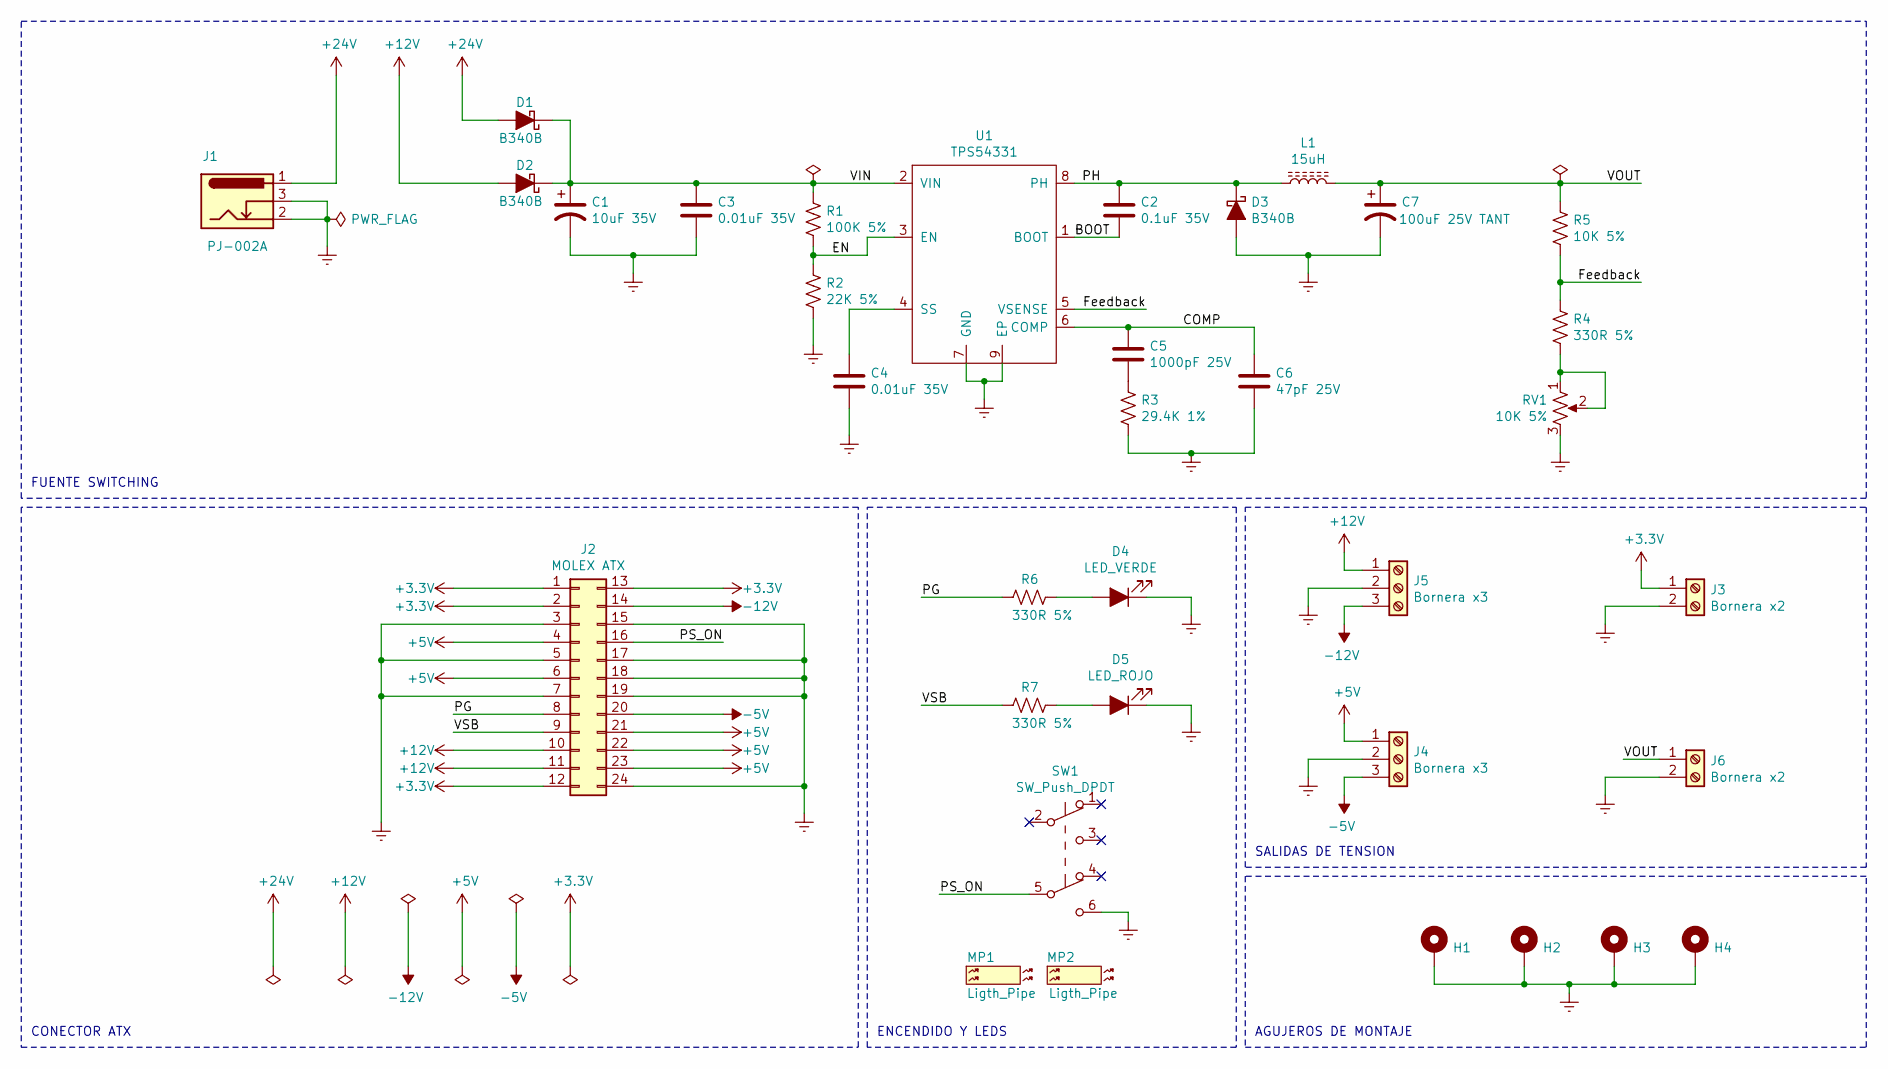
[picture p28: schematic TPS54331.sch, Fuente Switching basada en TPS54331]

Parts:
C1: 10uF 35V; CP_Elec_5x5.8; Manufacturer P/N EEE-HB1V100R; Digikey P/N PCE4153CT-ND
C2: 0.1uF 35V; C_0805_2012Metric; Manufacturer P/N 08055C104KAT2A; Digikey P/N 478-1395-1-ND
C3, C4: 0.01uF 35V; C_0805_2012Metric; Manufacturer P/N CC0805KRX7R9BB103; Digikey P/N 311-1136-1-ND
C5: 1000pF 25V; C_0805_2012Metric; Manufacturer P/N CL21B102KBANNNC; Digikey P/N 1276-1020-1-ND
C6: 47pF 25V; C_0805_2012Metric; Manufacturer P/N CL21C470JBANNNC; Digikey P/N 1276-1156-1-ND
C7: 100uF 25V TANT; CP_EIA-7343-43_Kemet-X; Manufacturer P/N T491X107K025AT; Digikey P/N 399-8410-1-ND
D1, D2, D3: B340B; D_SMB; Manufacturer P/N B340B-13-F; Digikey P/N B340B-FDICT-ND
D4: LED_VERDE; LED_0805_2012Metric; Manufacturer P/N LTST-C170KGKT; Digikey P/N 160-1414-1-ND
D5: LED_ROJO; LED_0805_2012Metric; Manufacturer P/N LTST-C171KRKT; Digikey P/N 160-1427-2-ND
H1, H2, H3, H4: MountingHole_Pad; MountingHole_3.2mm_M3_Pad
J1: PJ-002A; Manufacturer P/N PJ-002A; Digikey P/N CP-002A-ND
J2: MOLEX ATX; Molex_0039301240; Manufacturer P/N 0039299242; Digikey P/N WM7334-ND
J3, J6: Bornera x2; 796644-2; Manufacturer P/N 796644-2; Digikey P/N A98248-ND
J4, J5: Bornera x3; 796644-3; Manufacturer P/N 796644-3; Digikey P/N A98249-ND
L1: 15uH; SRR1260; Manufacturer P/N SRR1260-150M; Digikey P/N SRR1260-150MCT-ND
MP1, MP2: Ligth_Pipe; NoFootprint; Manufacturer P/N LFB063CTP; Digikey P/N LFB063CTP-ND
R1: 100K 5%; R_0805_2012Metric; Manufacturer P/N RC0805JR-07100KL; Digikey P/N 311-100KARCT-ND
R2: 22K 5%; R_0805_2012Metric; Manufacturer P/N RC0805JR-0722KL; Digikey P/N 311-22KARCT-ND
R3: 29.4K 1%; R_0805_2012Metric; Manufacturer P/N RC0805FR-0729K4L; Digikey P/N 311-29.4KCRTR-ND
R4, R6, R7: 330R 5%; R_0805_2012Metric; Manufacturer P/N RC0805JR-07330RL; Digikey P/N 311-330RARCT-ND
R5: 10K 5%; R_0805_2012Metric; Manufacturer P/N RC0805JR-0710KL; Digikey P/N 311-10KARCT-ND
RV1: 10K 5%; PTV111-3; Manufacturer P/N PTV111-3415A-B103; Digikey P/N PTV111-3415A-B103-ND
SW1: SW_Push_DPDT; TL2230; Manufacturer P/N TL2230EEF140; Digikey P/N EG6031-ND
U1: TPS54331; SOIC-8-1EP_3.9x4.9mm_P1.27mm_EP2.29x3mm; Manufacturer P/N TPS54331DDAR; Digikey P/N 296-39419-1-ND

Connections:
+3V3: J2.1, J2.2, J2.12, J2.13, J3.1
+5V: J2.4, J2.6, J2.21, J2.22, J2.23, J4.1
+12V: D2.2 (A), J2.10, J2.11, J5.1
+24V: D1.2 (A), J1.1
-5V: J2.20, J4.3
-12V: J2.14, J5.3
/BOOT: C2.2, U1.1 (BOOT)
/COMP: C5.1, C6.1, U1.6 (COMP)
/EN: R1.2, R2.1, U1.3 (EN)
/Feedback: R4.1, R5.2, U1.5 (VSENSE)
/PG: J2.8, R6.2
/PH: C2.1, D3.1 (K), L1.1, U1.8 (PH)
/PS_ON: J2.16, SW1.5 (B)
/VIN: C1.1, C3.1, D1.1 (K), D2.1 (K), R1.1, U1.2 (VIN)
/VOUT: C7.1, J6.1, L1.2, R5.1
/VSB: J2.9, R7.2
Earth: C1.2, C3.2, C4.2, C6.2, C7.2, D3.2 (A), D4.1 (K), D5.1 (K), H1.1, H2.1, H3.1, H4.1, J1.2, J1.3, J2.3, J2.5, J2.7, J2.15, J2.17, J2.18, J2.19, J2.24, J3.2, J4.2, J5.2, J6.2, R2.2, R3.2, RV1.3, SW1.6 (C), U1.7 (GND), U1.9 (EP)
unnamed: C4.1, U1.4 (SS)
unnamed: C5.2, R3.1
unnamed: D4.2 (A), R6.1
unnamed: D5.2 (A), R7.1
unnamed: R4.2, RV1.1, RV1.2

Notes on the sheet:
ENCENDIDO Y LEDS
CONECTOR ATX
FUENTE SWITCHING
SALIDAS DE TENSION
AGUJEROS DE MONTAJE

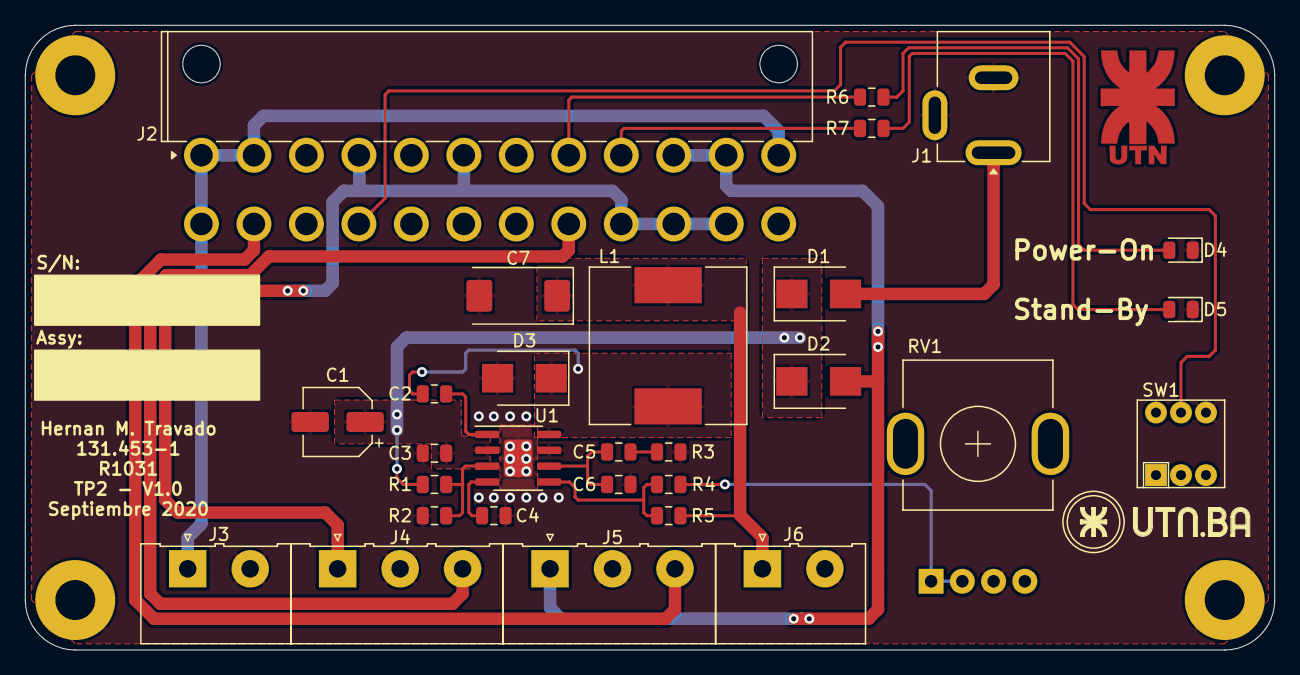
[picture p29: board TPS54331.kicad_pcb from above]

Board: 2 copper layers, 100.0 x 50.0 mm, 36 parts (0 on the bottom side), 22 nets.

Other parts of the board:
LogoUTN.BA-Letras: UTN.BA-Letras
